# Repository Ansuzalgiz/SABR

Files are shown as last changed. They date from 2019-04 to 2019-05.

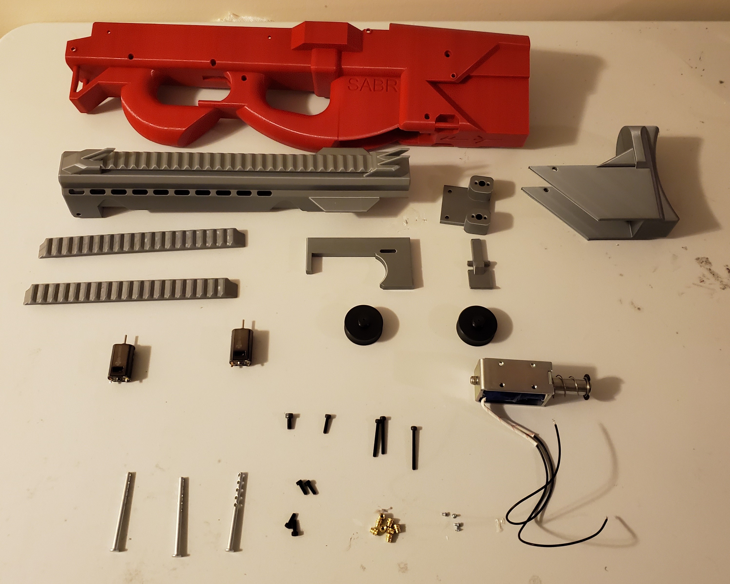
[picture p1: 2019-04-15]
Images/Parts.jpg

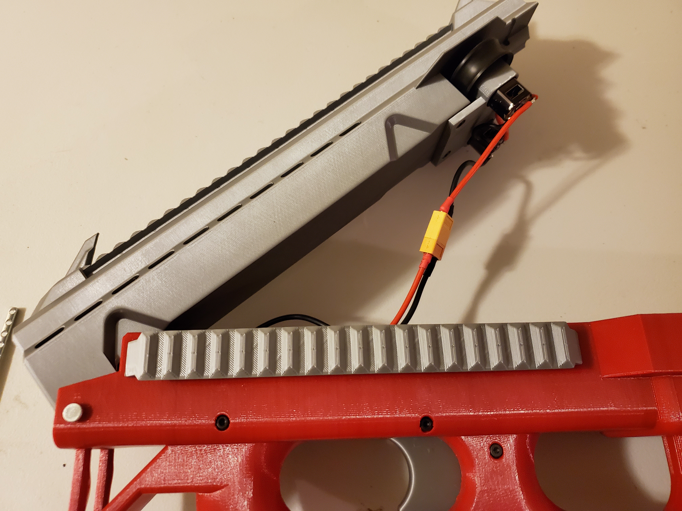
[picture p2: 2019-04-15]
Images/BarrelInstall.jpg

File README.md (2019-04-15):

# SABR

The SABR is a 3D printed Nerf SemiAutomatic Bullpup Rifle for full length darts. 

# Features
- Simple design: only 8 printed parts for the blaster
- Tooless access to the battery compartment, flywheel cage and barrel
- Dual stage trigger
- 41.5mm flywheel gap for the integral flywheel cage
- Full length dart feed guide
- FTW solenoid pusher
- Full length picatinny top rail
- Optional side picatinny rails
- Integrated sling mounts

# Required Parts

|Part |Quantity  |Description |
|---|---|---|
|Flywheel motors |2 |130 or 180 sized motors for flywheels [Purchase Link](https://outofdarts.com/collections/motors-2019/products/ood-kraken-motor) |
|Flywheels |2 |Flywheels [Purchase Link](https://www.containmentcrew.com/shop/cc/cc-inf/) |
|FTW Solenoid |1 |FTW Solenoid for the pusher |
|Microswitch | 2 | For activating the motors and solenoid [Purchase Link](https://outofdarts.com/collections/electronics/products/21a-microswitch-button-clone) |
|Silicone insulated wire  | | Wiring |
|Heat set threaded inserts| 10 | To hold in screws (McMaster 94180A333 for 100) |
|Compression Spring | 1 | For trigger (McMaster 9657K56 for 12) |
|Torsion Spring | 1 | For magazine release (McMaster 9271K579 for 6) |
|M4x10 Socket head screw  | 1 | For securing the solenoid |
|M3x10 Socket head screws | 7 | |
|M3x25 Socket head screws | 2 | Used for flywheel switch and trigger |
|M3x35 Socket head screw  | 1 | For magazine release |
|M2 screws | 4 | For motors |
|2 1/2" x 3/16" Pins | 3 | For securing the battery and stock (McMaster 98330A125 for 10) |

# Printing Parameters
Prototypes were printed using these parameters:
- PLA
- .3mm layer height
- .4mm nozzle
- 1.2mm vertical wall thickness
- No supports

# Assembly

[Assembly guide on the repository wiki](https://github.com/Ansuzalgiz/SABR/wiki/Assembly)

# Purchasing

I sell the [blaster and printed parts on Etsy.](http://etsy.com/shop/Ansuzalgiz)

# Contributing
The project was designed using Fusion 360, under their hobbyist license. 

# Attributions
This project uses the [FTW Solenoid by FlywheelTheWorld](https://www.thingiverse.com/thing:3518739) and the [FTW Solenoid Pusher Head by FlywheelTheWorld](https://www.thingiverse.com/thing:3307908)

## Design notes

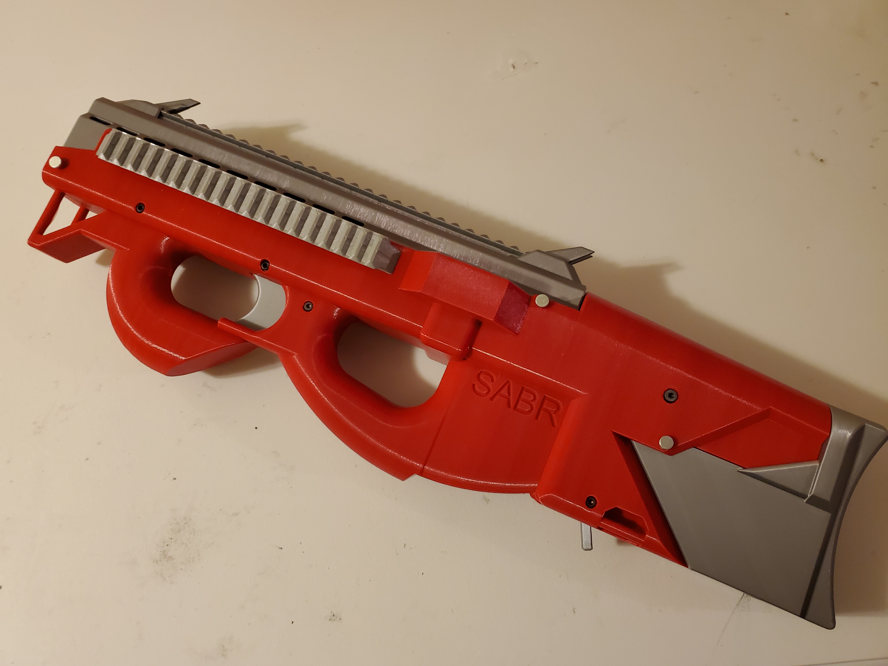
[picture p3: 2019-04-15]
Images/Finished.jpg

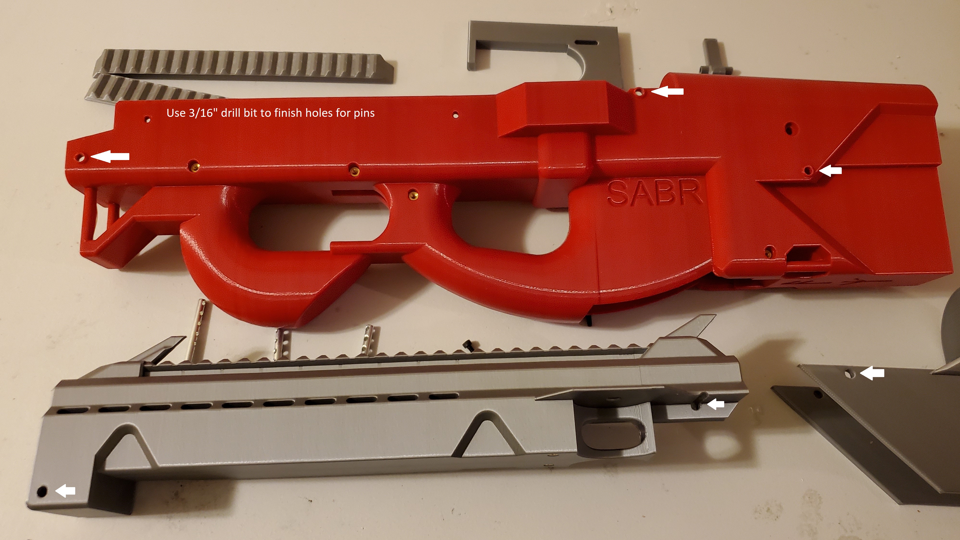
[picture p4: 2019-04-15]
Images/DrillForPins.jpg

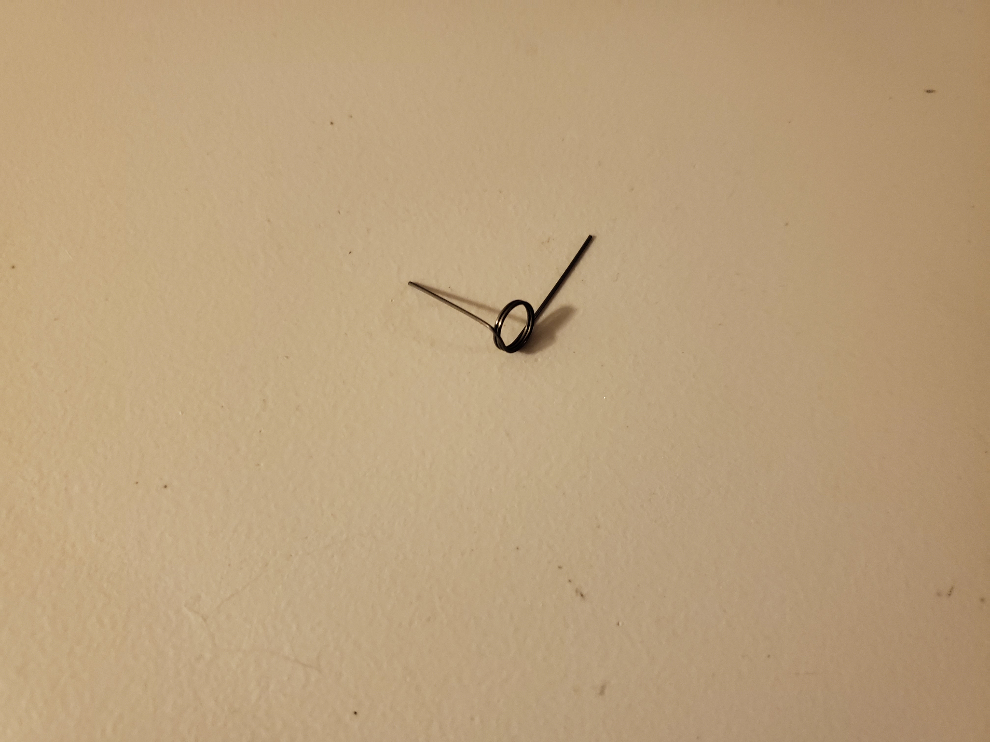
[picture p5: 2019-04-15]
Images/MagReleaseSpringBend.jpg

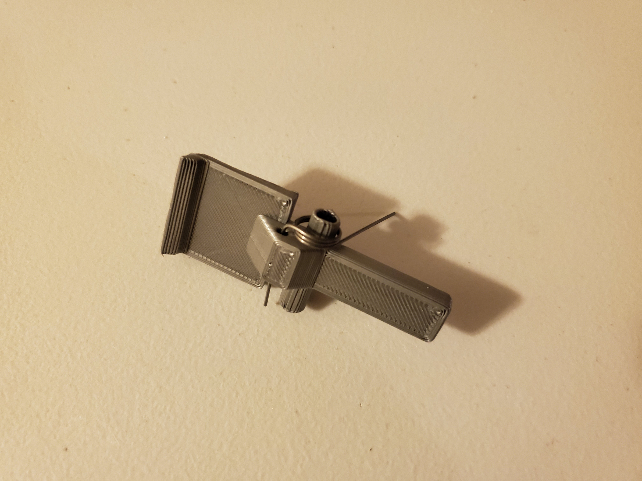
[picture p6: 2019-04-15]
Images/MagRelease.jpg

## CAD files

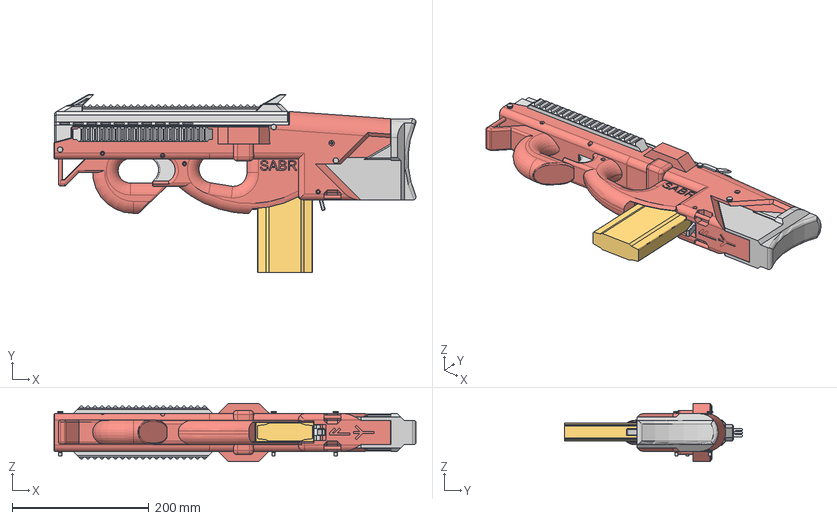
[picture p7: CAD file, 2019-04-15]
SABR.step
529.1 x 260.3 x 85.0 mm
Receiver
Trigger
FlywheelCage
NerfMagazine
Barrel
MagRelease
Frame Back Plate
Frame Plate
Magnet Body
C-Ring
Nut/pusher
98330A125 x 3
Stock
Rail x 2
180Motor x 2
Case x 2
NCTab x 2
ComTab x 2
NOTab x 2
Lid x 2
Button x 2
130Motor
CC-Inferno x 2

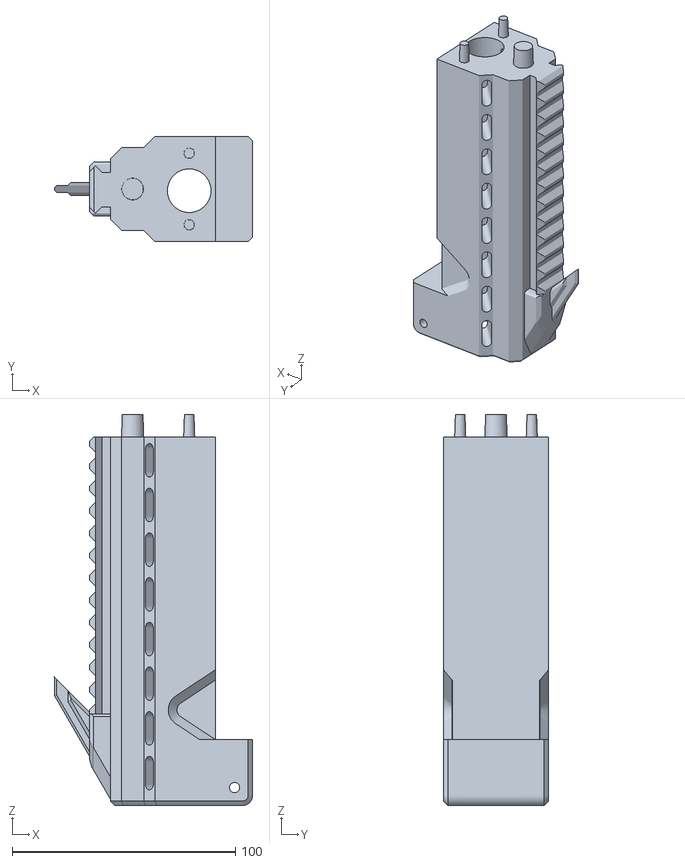
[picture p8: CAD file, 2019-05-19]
STL/Barrel Split/Barrel Front.stl
88.7 x 47.0 x 175.0

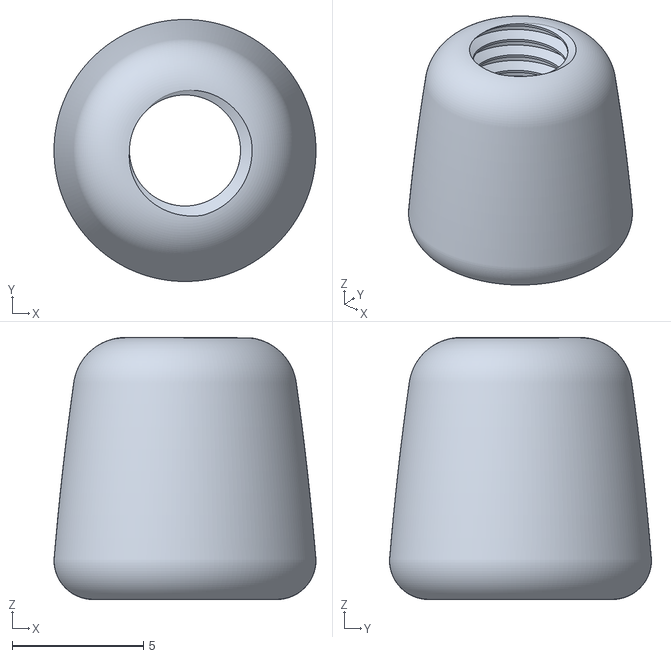
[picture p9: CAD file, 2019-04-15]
STL/FTW_Solenoid_Pusher_Head.stl
10.00 x 10.00 x 10.00

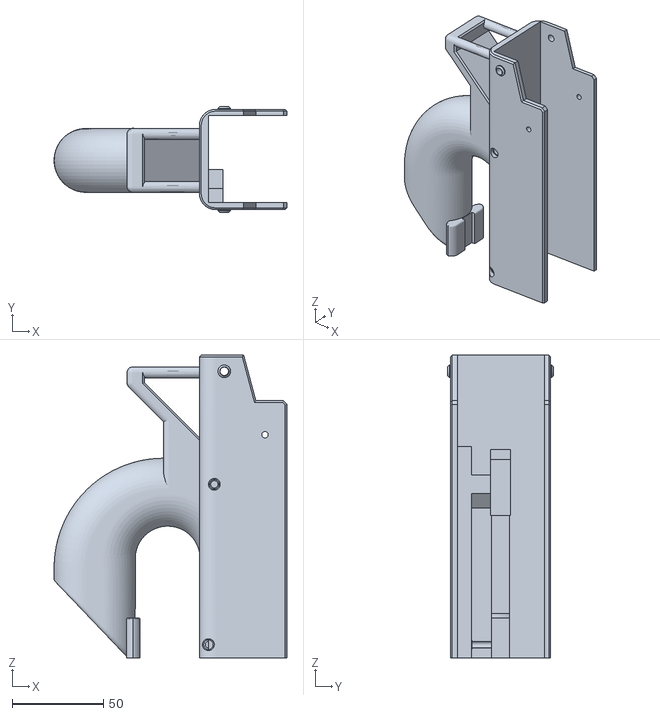
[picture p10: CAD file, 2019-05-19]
STL/Reciever Split/Reciever_Front.stl
127.6 x 58.0 x 166.0

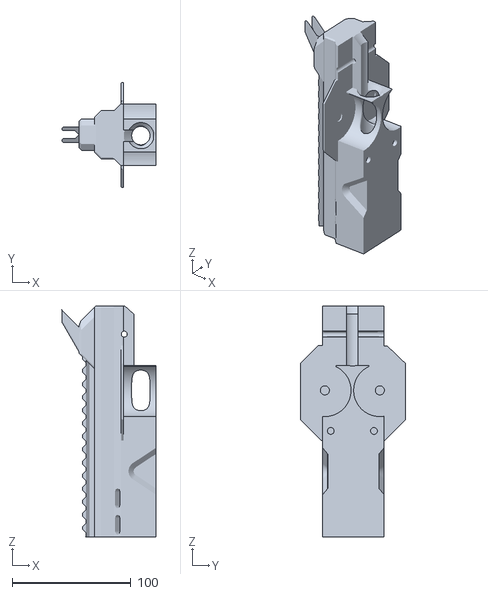
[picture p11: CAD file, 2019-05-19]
STL/Barrel Split/Barrel Rear.stl
79.5 x 89.0 x 194.9

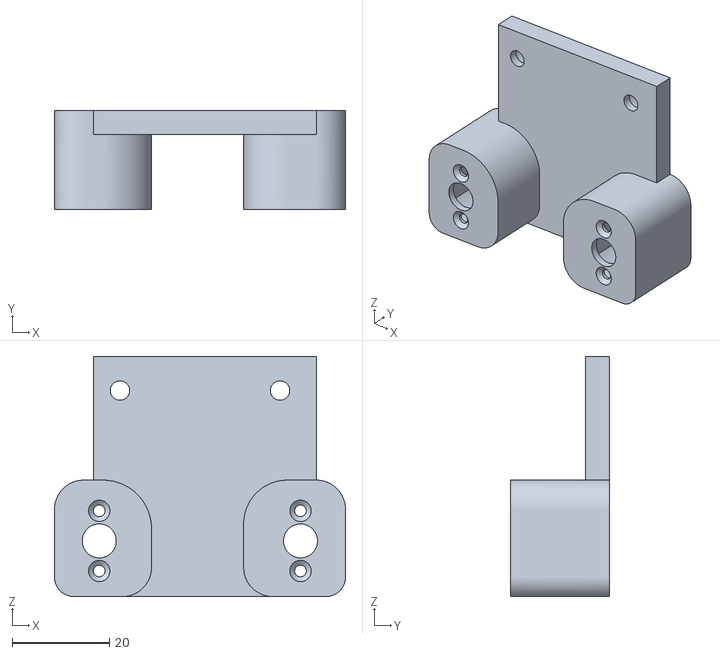
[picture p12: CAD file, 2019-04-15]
STL/FlywheelCage.stl
60.0 x 20.5 x 49.5

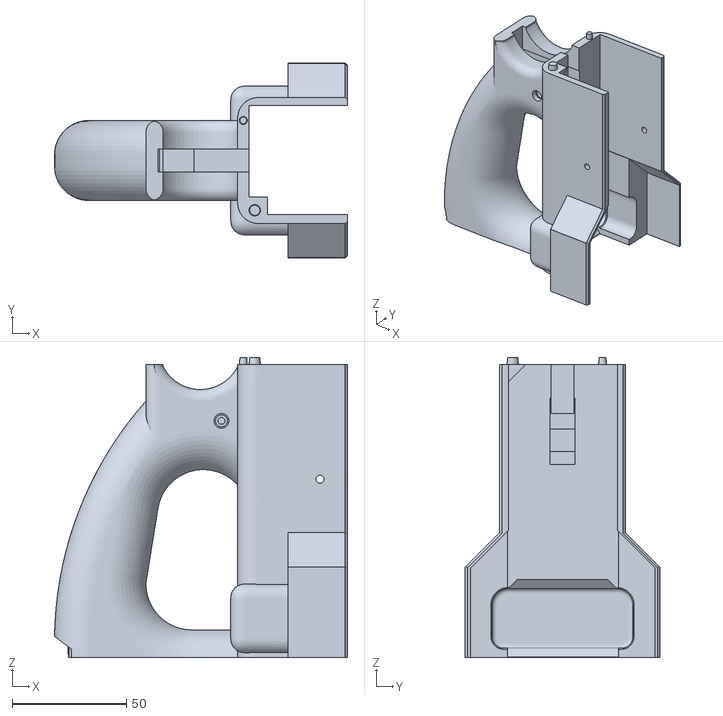
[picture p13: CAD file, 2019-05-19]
STL/Reciever Split/Reciever_Mid.stl
128.0 x 85.0 x 131.1

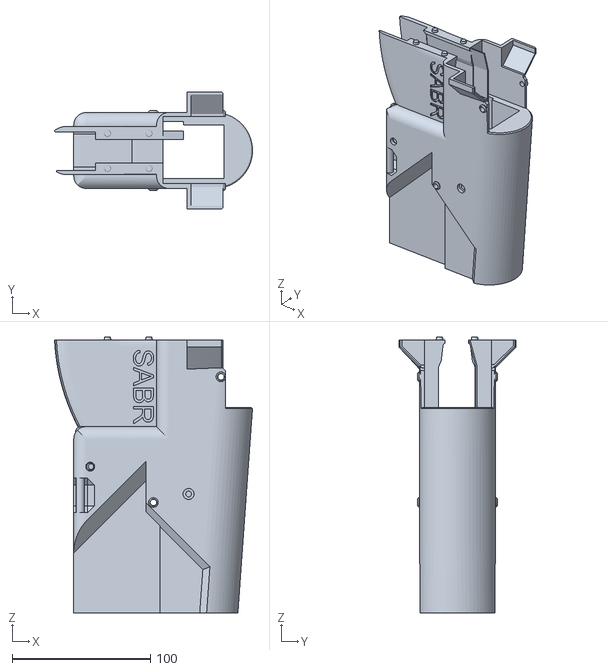
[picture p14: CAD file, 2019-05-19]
STL/Reciever Split/Reciever_Rear.stl
143.4 x 85.0 x 199.9

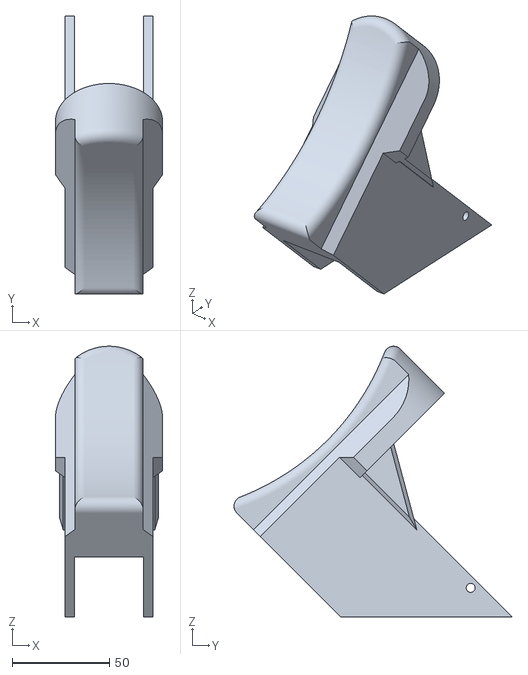
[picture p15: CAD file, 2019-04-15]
STL/Stock.stl
55.0 x 142.8 x 139.0

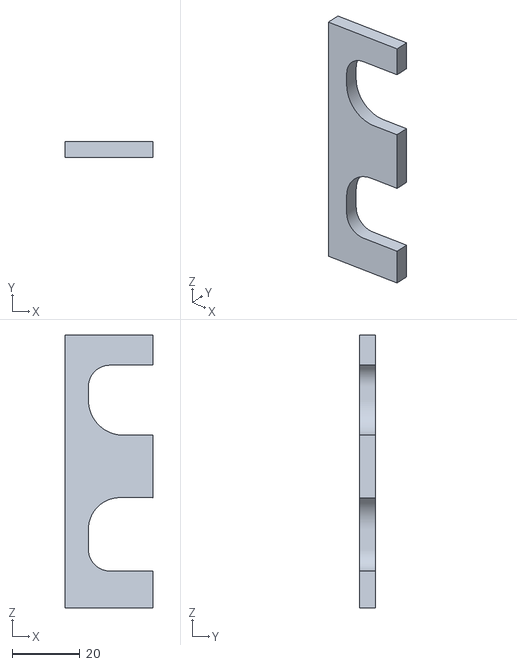
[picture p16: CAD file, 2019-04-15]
STL/FlywheelShim.stl
25.9 x 4.60 x 80.4

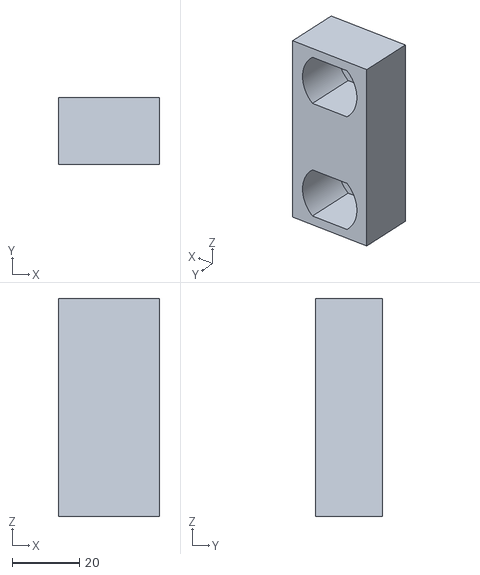
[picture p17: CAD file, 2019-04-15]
STL/180MotorSupport.stl
30.0 x 20.0 x 65.0

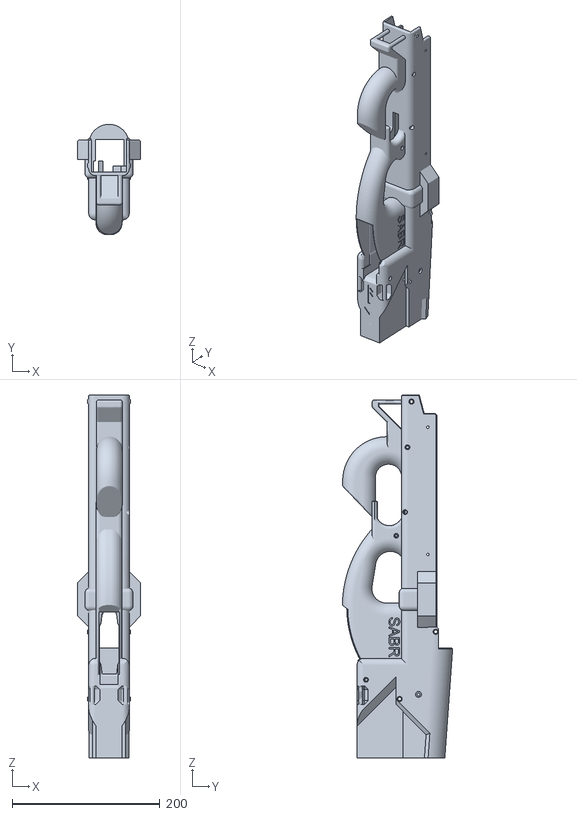
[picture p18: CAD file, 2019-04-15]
STL/Receiver.stl
85.0 x 149.5 x 492.0

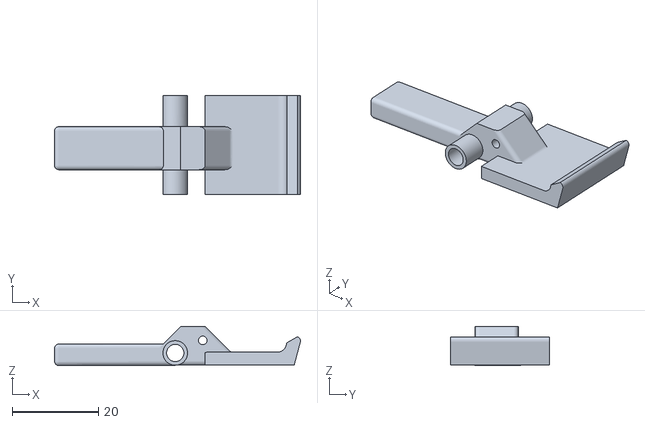
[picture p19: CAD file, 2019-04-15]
STL/MagRelease.stl
57.1 x 23.0 x 9.09

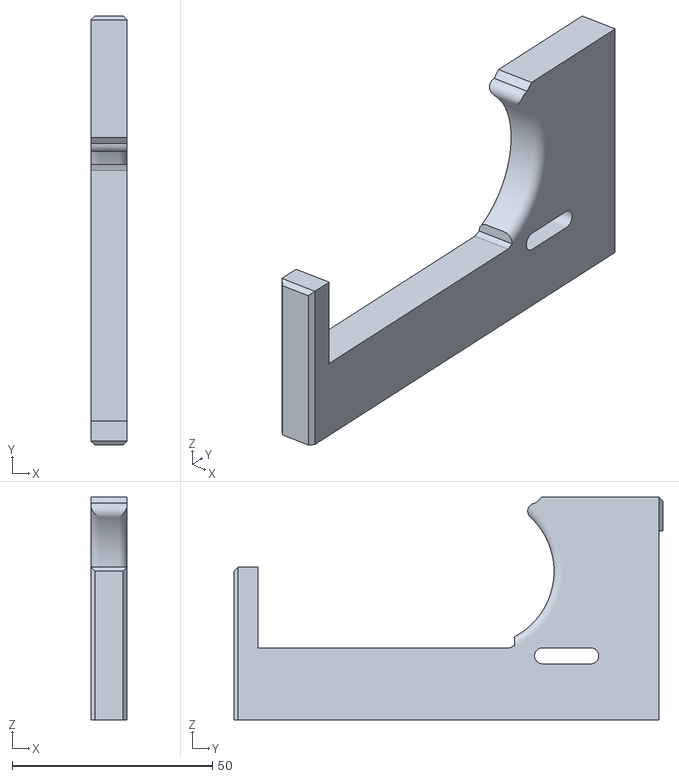
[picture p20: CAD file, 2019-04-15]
STL/Trigger.stl
9.00 x 107.0 x 55.5

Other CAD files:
STL/Barrel.stl
STL/130MotorSupport.stl
STL/Rail.stl

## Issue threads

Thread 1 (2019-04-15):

Splitting Reciever

timmit99, 2019-04-15:
What printer are you printing this on? At almost 500mm in length the receiver would need to be cut down into 2-3 pieces to be manageable for most standard printers (200mm-220mm).  Even my Wilson 2 at 200x300x200 would need to do this in two parts. What software was used to design this? I would be willing to work on splitting this file p if i could get the source files to make this easier on the average person.

Thanks,

Ansuzalgiz, 2019-05-19:
Pull request for splitting large parts has been merged.

Closed 2019-05-19.

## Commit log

2019-04-15 Update assembly link
2019-04-18 Large Part Splits
    Split the larget components ( Reciever and Barrel) into parts with indexing lugs for printing on non 500+mm Axis printers. The rear section of the reciever is 199.9mm so it would be best on a 250mm p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
    [Barrel Front.stl, Barrel Rear.stl, Reciever_Front.stl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]
2019-05-15 Files rotated for proper printing orientation
    I rotated the parts in Meshmixer and have re-exported them.
    Let me know if you need any further changes
    [Barrel Front.stl, Barrel Rear.stl, Reciever_Front.stl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]
